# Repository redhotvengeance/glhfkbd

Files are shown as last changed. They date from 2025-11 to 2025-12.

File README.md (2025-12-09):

# glhfkbd

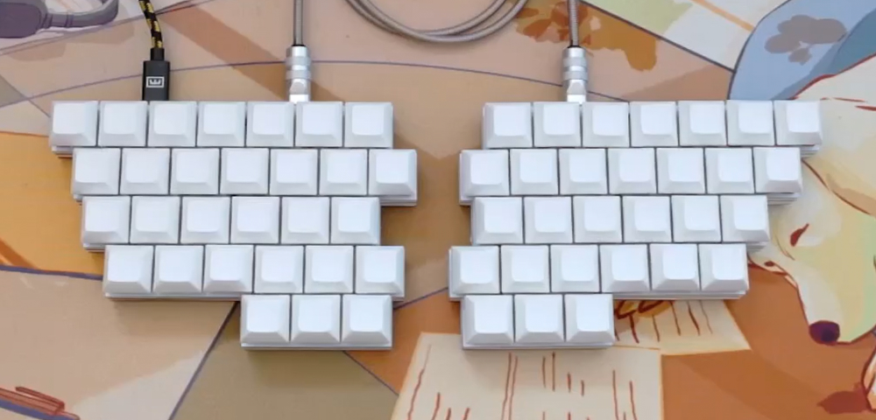
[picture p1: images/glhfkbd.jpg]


A custom, split keyboard.

Features:
- Extremely minimalist design -- no bevels, no edges, just keys!
- Split body, for da ergonomics
- Row-staggered, for da muscle memory
- A "Y" and "B" key on both halves, for da bad typists
- Supports hotswap MX sockets
- Fully embedded electronics -- no dev boards!
- USB-C for the wired interconnect -- no live TRRS shorts!
- Either side can act as the host
- Driven by QMK firmware and fully customizable

## PCB

The PCB is all one unit, despite both halves of the keyboard being asymmetrical. Mouse bites are used to easily separate pieces. All gerbers are provided in this repo.

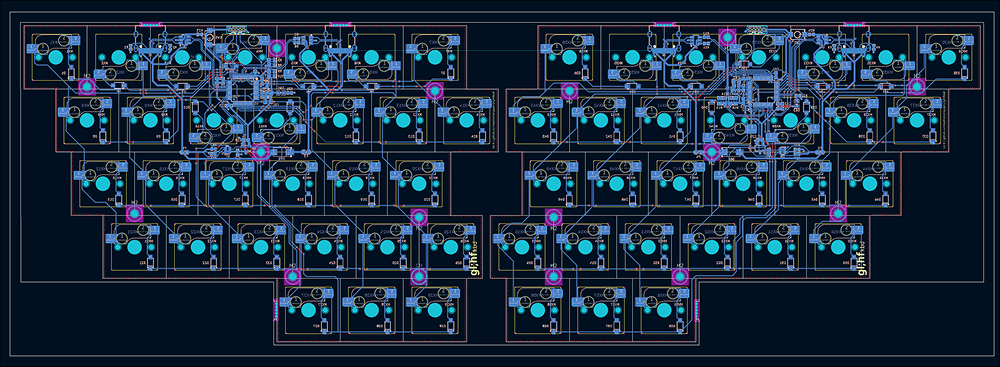
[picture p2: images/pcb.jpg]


All electronics are embedded into the board itself. This eliminates the need for a dev board, but requires assembly by a PCB manufacturer. BOM and position files are provided in this repo.

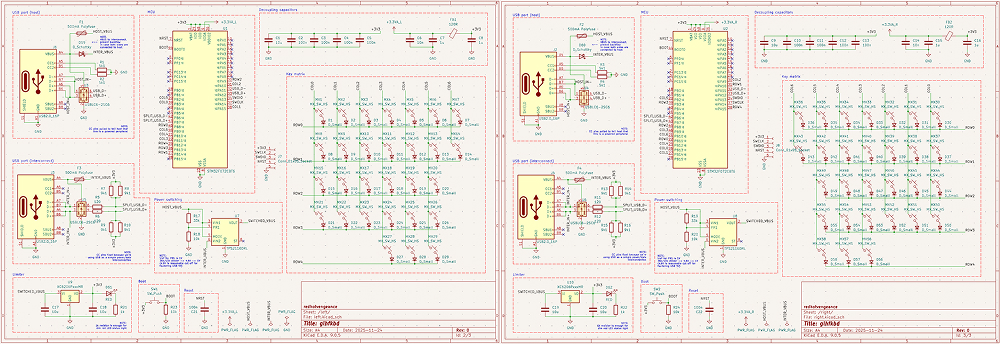
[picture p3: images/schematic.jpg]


## Case

All pieces for the case are provided as STEP files in this repo, with the exception of the switch plates, which are provided as PCB files so they can be manufactored in FR4.

### Switch plates (required)

Found in the `pcb` folder. Should be printed as non-copper and non-trace PCBs.

### Filler layer (optional)

3D printed layer that sites between the plates and PCBs (to fill the space between switches). Used for aesthetics and sound.

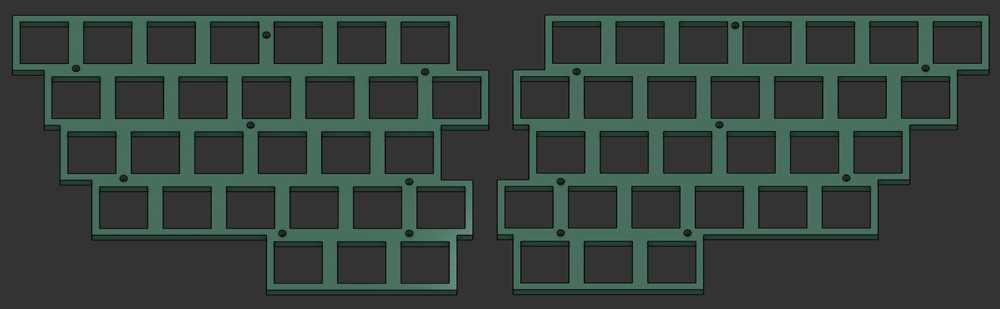
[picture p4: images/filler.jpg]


### Standoff layer (required)

Used to mount the PCBs and plates to the base. Can be easily 3D printed. Needs heat-set inserts added.

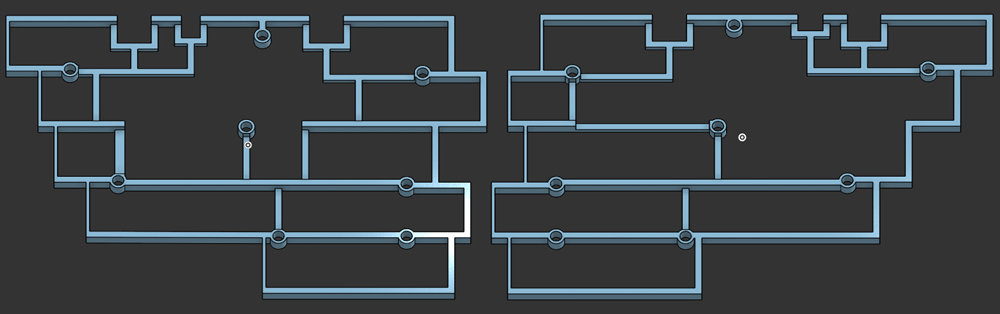
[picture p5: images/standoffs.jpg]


### Base (required)

Bottom of the keyboard. Can be 3D printed. Should have rubber feet added for stability.

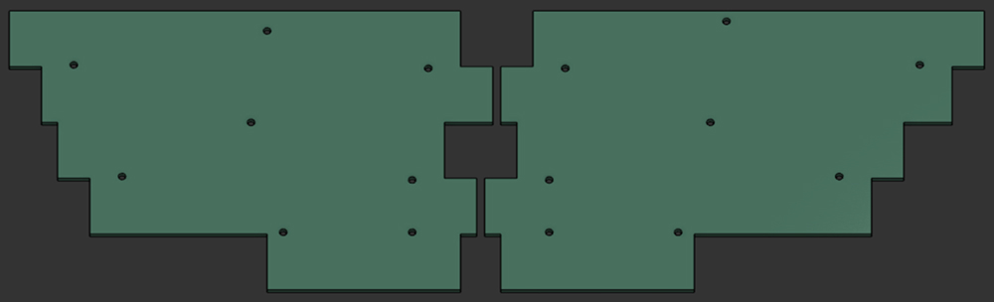
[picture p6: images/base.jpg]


As an upgrade, the base can be laser cut from metal. This adds weight, quality, and improved sound. I suggest using a ferrous metal (like carbon steel) so that each keyboard half can be easily attached to a magsafe stand for easy tenting.

## Sharing

Fully open source. Feel free to build it yourself.

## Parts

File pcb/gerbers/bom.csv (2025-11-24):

Designator | Footprint | Quantity | Value | LCSC Part #
C1, C17, C18, C19, C20, C9 | cap_10uf | 6 | 10u | C15525
C10, C11, C12, C13, C2, C21, C22, C3, C4, C5 | cap_100nf | 10 | 100n | C307331
C14, C6 | cap_10nf | 2 | 10n | C15195
C15, C16, C7, C8 | cap_1uf | 4 | 1u | C52923
D1, D10, D11, D12, D13, D14, D15, D16, D17, D18, D19, D2, D20, D21, D22, D23, D24, D25, D26, D27, D28, D29, D3, D30, D31, D32, D33, D34, D35, D36, D37, D38, D39, D4, D40, D41, D42, D43, D44, D45, D46, D47, D48, D49, D5, D50, D51, D52, D53, D54, D55, D56, D57, D58, D6, D7, D8, D9 | diode_sod123 | 58 | D_Small | C81598
D59, D60 | schottky | 2 | D_Schottky | C22452
D61, D62 | led | 2 | RED | C2286
F1, F2, F3, F4 | fuse_500ma | 4 | 500mA Polyfuse | C210357
FB1, FB2 | ferrite | 2 | 120R | C87063
J1, J2, J3, J4 | usb-c | 4 | USB2.0_16P | C165948
R1, R2, R3, R4 | res_5k1 | 4 | 5k1 | C25905
R10, R13, R14, R15, R16, R7, R8, R9 | res_9k1 | 8 | 9k1 | C23260
R11, R12, R5, R6 | res_120 | 4 | 120 | C25079
R17, R19 | res_33k | 2 | 33k | C25779
R18, R20, R23, R24 | res_10k | 4 | 10k | C25744
R21, R22 | res_1k | 2 | 1k | C11702
SW1, SW2 | switch | 2 | SW_Push | C720477
U1, U2 | stm32 | 2 | STM32F072CBT6 | C81720
U10, U9 | xc6206 | 2 | XC6206PxxxMR | C5446
U3, U4, U5, U6 | usblc6-2sc6 | 4 | USBLC6-2SC6 | C2827654
U7, U8 | tps2116drlr | 2 | TPS2116DRL | C3235557

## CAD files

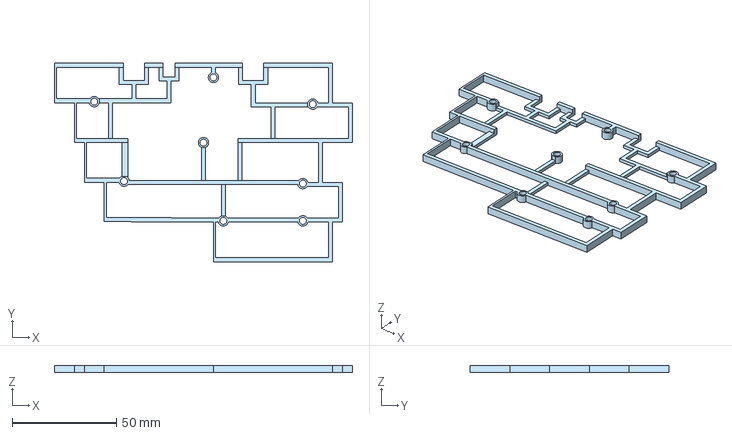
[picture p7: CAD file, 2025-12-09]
case/step/standoff_left.step
142.9 x 95.2 x 3.50 mm

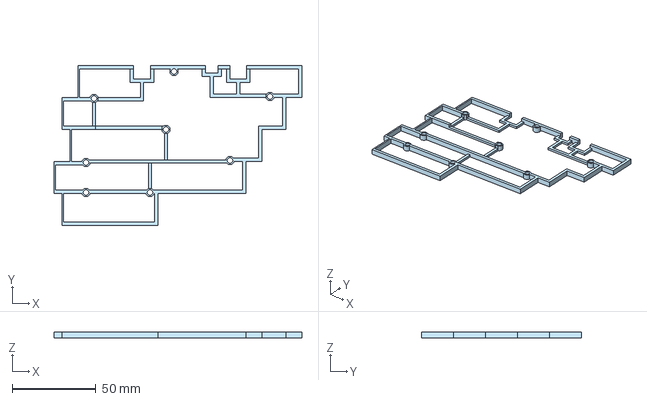
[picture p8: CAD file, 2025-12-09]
case/step/standoff_right.step
147.6 x 95.2 x 3.50 mm

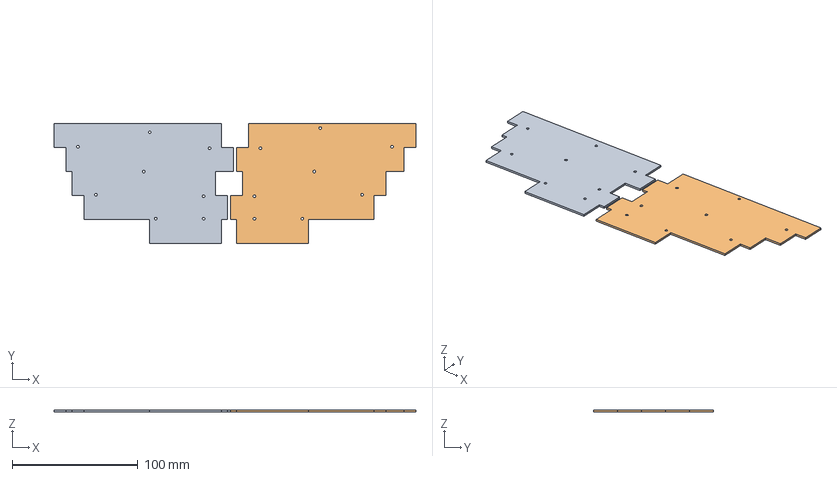
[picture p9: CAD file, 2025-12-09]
case/step/bottom.step
288.1 x 95.3 x 1.51 mm
bottom_PCB_1
bottom_PCB_2

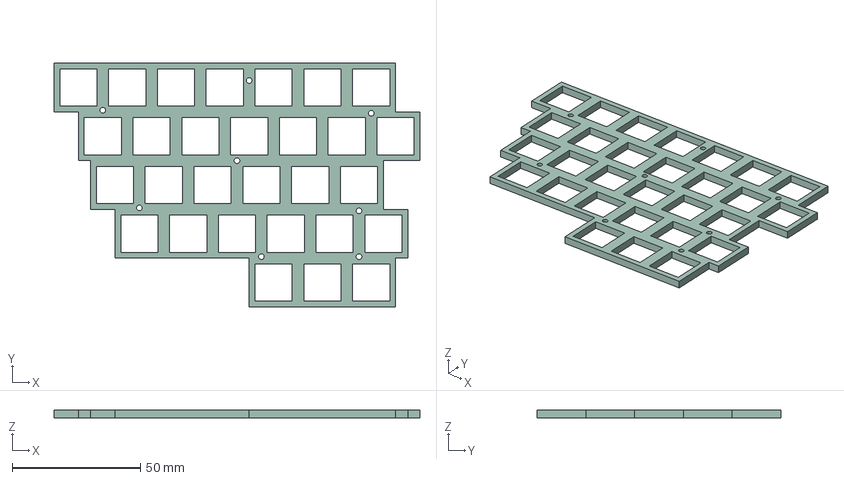
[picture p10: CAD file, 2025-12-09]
case/step/filler_left.step
142.9 x 95.3 x 3.00 mm

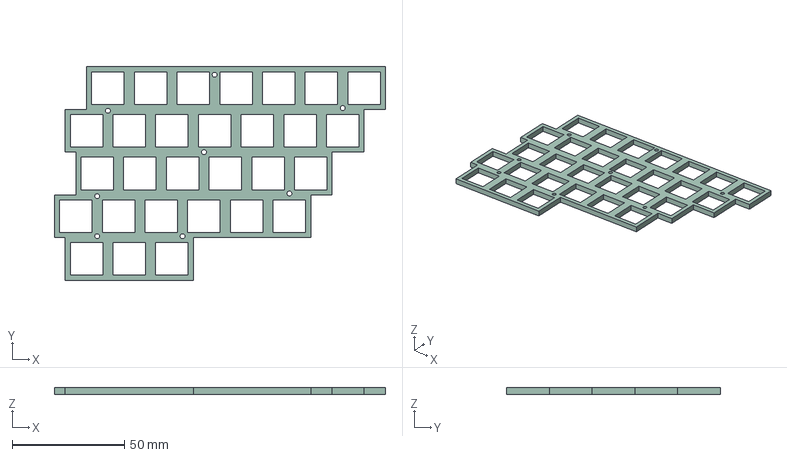
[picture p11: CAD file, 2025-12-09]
case/step/filler_right.step
147.6 x 95.2 x 3.00 mm

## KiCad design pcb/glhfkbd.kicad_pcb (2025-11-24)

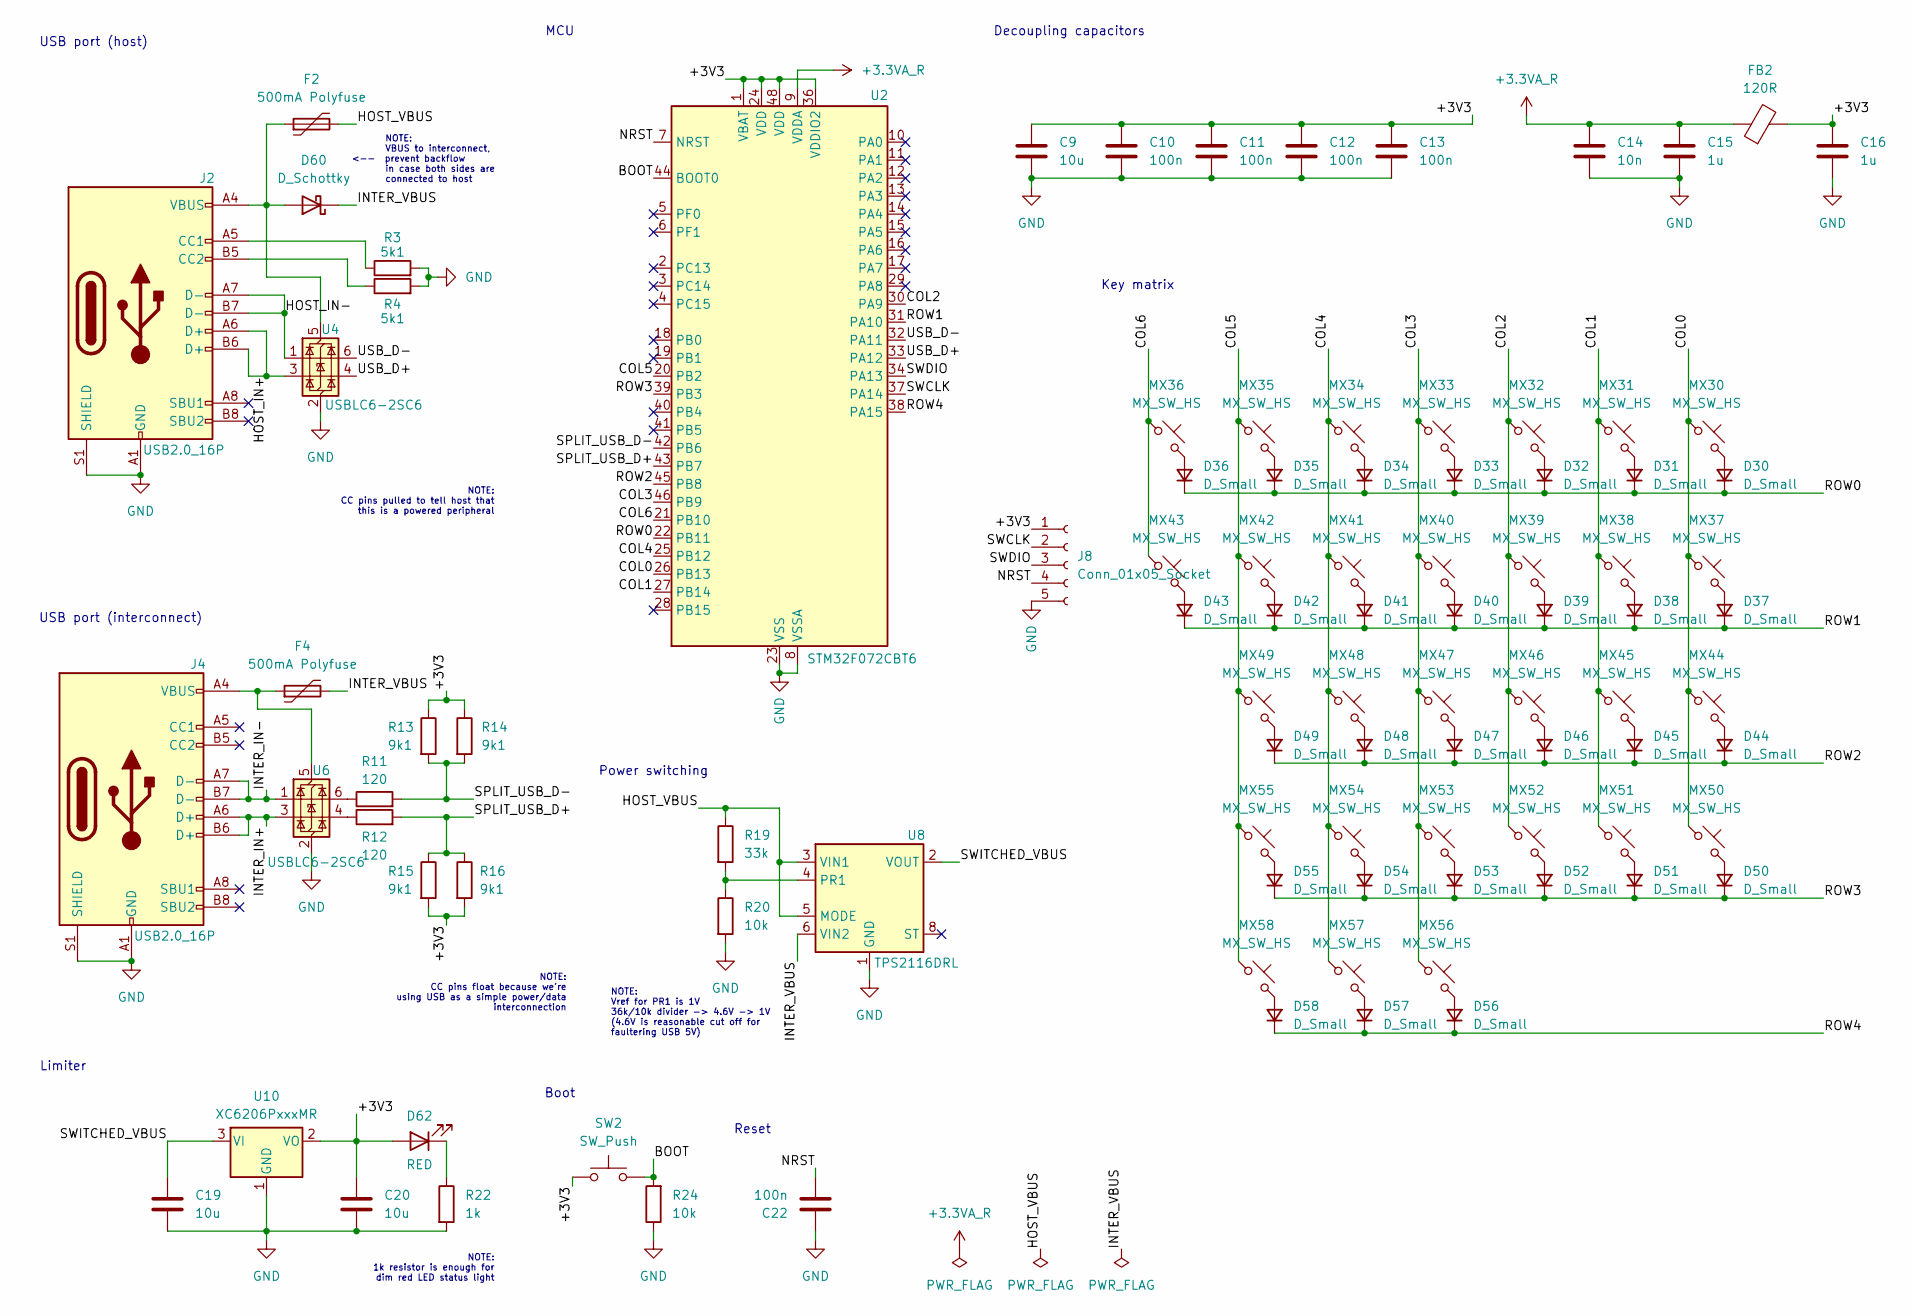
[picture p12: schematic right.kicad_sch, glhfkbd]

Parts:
C9, C19, C20: 10u; cap_10uf; Manufacturer Part CL05A106MQ5NUNC; LCSC C15525
C10, C11, C12, C13, C22: 100n; cap_100nf; Manufacturer Part CL05B104KB54PNC; LCSC C307331
C14: 10n; cap_10nf; Manufacturer Part CL05B103KB5NNNC; LCSC C15195
C15, C16: 1u; cap_1uf; Manufacturer Part CL05A105KA5NQNC; LCSC C52923
D30, D31, D32, D33, D34, D35, D36, D37, D38, D39, D40, D41, D42, D43, D44, D45, D46, D47, D48, D49, D50, D51, D52, D53, D54, D55, D56, D57, D58: D_Small; diode_sod123; Manufacturer Part 1N4148W; LCSC C81598
D60: D_Schottky; schottky; Manufacturer Part SS54; LCSC C22452
D62: RED; led; Manufacturer Part KT-0603R; LCSC C2286
F2, F4: 500mA Polyfuse; fuse_500ma; Manufacturer Part MF-FSMF050X-2; LCSC C210357
FB2: 120R; ferrite; Manufacturer Part BLM18SG260TN1D; LCSC C87063
J2, J4: USB2.0_16P; usb-c; Manufacturer Part TYPE-C-31-M-12; LCSC C165948
J8: Conn_01x05_Socket; PinHeader_1x05_P1.00mm_Vertical
MX30, MX31, MX32, MX33, MX34, MX35, MX36, MX37, MX38, MX39, MX40, MX41, MX42, MX43, MX44, MX45, MX46, MX47, MX48, MX49, MX50, MX51, MX52, MX53, MX54, MX55, MX56, MX57, MX58: MX_SW_HS; SW_MX_HS_CPG151101S11_1u
R3, R4: 5k1; res_5k1; Manufacturer Part 0402WGF5101TCE; LCSC C25905
R11, R12: 120; res_120; LCSC C25079
R13, R14, R15, R16: 9k1; res_9k1; LCSC C23260
R19: 33k; res_33k; Manufacturer Part 0402WGF3302TCE; LCSC C25779
R20, R24: 10k; res_10k; Manufacturer Part 0402WGF1002TCE; LCSC C25744
R22: 1k; res_1k; Manufacturer Part 0402WGF1001TCE; LCSC C11702
SW2: SW_Push; switch; Manufacturer Part TS-1088-AR02016; LCSC C720477
U2: STM32F072CBT6; stm32; Manufacturer Part STM32F072CBT6; LCSC C81720
U4, U6: USBLC6-2SC6; usblc6-2sc6; Manufacturer Part USBLC6-2SC6; LCSC C2827654
U8: TPS2116DRL; tps2116drlr; Manufacturer Part TPS2116DRLR; LCSC C3235557
U10: XC6206PxxxMR; xc6206; Manufacturer Part XC6206P332MR-G; LCSC C5446

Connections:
+3.3VA_R: C14.1, C15.1, FB2.1, U2.9 (VDDA)
/right/+3V3: C9.1, C10.1, C11.1, C12.1, C13.1, C16.1, C20.1, D62.2 (A), FB2.2, J8.1, R13.1, R14.1, R15.2, R16.2, SW2.1, U2.1 (VBAT), U2.24 (VDD), U2.36 (VDDIO2), U2.48 (VDD), U10.2 (VO)
/right/BOOT: R24.2, SW2.2, U2.44 (BOOT0)
/right/COL0: MX30.1, MX37.1, MX44.1, MX50.1, U2.26 (PB13)
/right/COL1: MX31.1, MX38.1, MX45.1, MX51.1, U2.27 (PB14)
/right/COL2: MX32.1, MX39.1, MX46.1, MX52.1, U2.30 (PA9)
/right/COL3: MX33.1, MX40.1, MX47.1, MX53.1, MX56.1, U2.46 (PB9)
/right/COL4: MX34.1, MX41.1, MX48.1, MX54.1, MX57.1, U2.25 (PB12)
/right/COL5: MX35.1, MX42.1, MX49.1, MX55.1, MX58.1, U2.20 (PB2)
/right/COL6: MX36.1, MX43.1, U2.21 (PB10)
/right/HOST_IN+: J2.A6 (D+), J2.B6 (D+), U4.3 (I/O2)
/right/HOST_IN-: J2.A7 (D-), J2.B7 (D-), U4.1 (I/O1)
/right/HOST_VBUS: F2.2, R19.1, U8.3 (VIN1), U8.5 (MODE)
/right/INTER_IN+: J4.A6 (D+), J4.B6 (D+), U6.3 (I/O2)
/right/INTER_IN-: J4.A7 (D-), J4.B7 (D-), U6.1 (I/O1)
/right/INTER_VBUS: D60.1 (K), F4.2, U8.6 (VIN2)
/right/NRST: C22.1, J8.4, U2.7 (NRST)
/right/ROW0: D30.1 (K), D31.1 (K), D32.1 (K), D33.1 (K), D34.1 (K), D35.1 (K), D36.1 (K), U2.22 (PB11)
/right/ROW1: D37.1 (K), D38.1 (K), D39.1 (K), D40.1 (K), D41.1 (K), D42.1 (K), D43.1 (K), U2.31 (PA10)
/right/ROW2: D44.1 (K), D45.1 (K), D46.1 (K), D47.1 (K), D48.1 (K), D49.1 (K), U2.45 (PB8)
/right/ROW3: D50.1 (K), D51.1 (K), D52.1 (K), D53.1 (K), D54.1 (K), D55.1 (K), U2.39 (PB3)
/right/ROW4: D56.1 (K), D57.1 (K), D58.1 (K), U2.38 (PA15)
/right/SPLIT_USB_D+: R12.2, R15.1, R16.1, U2.43 (PB7)
/right/SPLIT_USB_D-: R11.2, R13.2, R14.2, U2.42 (PB6)
/right/SWCLK: J8.2, U2.37 (PA14)
/right/SWDIO: J8.3, U2.34 (PA13)
/right/SWITCHED_VBUS: C19.1, U8.2 (VOUT), U8.7 (VOUT), U10.3 (VI)
/right/USB_D+: U2.33 (PA12), U4.4 (I/O2)
/right/USB_D-: U2.32 (PA11), U4.6 (I/O1)
GND: C9.2, C10.2, C11.2, C12.2, C13.2, C14.2, C15.2, C16.2, C19.2, C20.2, C22.2, J2.A1 (GND), J2.A12 (GND), J2.B1 (GND), J2.B12 (GND), J2.S1 (SHIELD), J4.A1 (GND), J4.A12 (GND), J4.B1 (GND), J4.B12 (GND), J4.S1 (SHIELD), J8.5, R3.2, R4.2, R20.2, R22.2, R24.1, U2.8 (VSSA), U2.23 (VSS), U2.35 (VSS), U2.47 (VSS), U4.2 (GND), U6.2 (GND), U8.1 (GND), U10.1 (GND); also elsewhere on the board
unnamed: D30.2 (A), MX30.2
unnamed: D31.2 (A), MX31.2
unnamed: D32.2 (A), MX32.2
unnamed: D33.2 (A), MX33.2
unnamed: D34.2 (A), MX34.2
unnamed: D35.2 (A), MX35.2
unnamed: D36.2 (A), MX36.2
unnamed: D37.2 (A), MX37.2
unnamed: D38.2 (A), MX38.2
unnamed: D39.2 (A), MX39.2
unnamed: D40.2 (A), MX40.2
unnamed: D41.2 (A), MX41.2
unnamed: D42.2 (A), MX42.2
unnamed: D43.2 (A), MX43.2
unnamed: D44.2 (A), MX44.2
unnamed: D45.2 (A), MX45.2
unnamed: D46.2 (A), MX46.2
unnamed: D47.2 (A), MX47.2
unnamed: D48.2 (A), MX48.2
unnamed: D49.2 (A), MX49.2
unnamed: D50.2 (A), MX50.2
unnamed: D51.2 (A), MX51.2
unnamed: D52.2 (A), MX52.2
unnamed: D53.2 (A), MX53.2
unnamed: D54.2 (A), MX54.2
unnamed: D55.2 (A), MX55.2
unnamed: D56.2 (A), MX56.2
unnamed: D57.2 (A), MX57.2
unnamed: D58.2 (A), MX58.2
unnamed: D60.2 (A), F2.1, J2.A4 (VBUS), J2.A9 (VBUS), J2.B4 (VBUS), J2.B9 (VBUS), U4.5 (VBUS)
unnamed: D62.1 (K), R22.1
unnamed: J2.A5 (CC1), R3.1
unnamed: J2.B5 (CC2), R4.1
unnamed: R11.1, U6.6 (I/O1)
unnamed: R12.1, U6.4 (I/O2)
unnamed: F4.1, J4.A4 (VBUS), J4.A9 (VBUS), J4.B4 (VBUS), J4.B9 (VBUS), U6.5 (VBUS)
unnamed: R19.2, R20.1, U8.4 (PR1)

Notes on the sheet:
USB port (interconnect)
NOTE: CC pins float because we're using USB as a simple power/data interconnection
Power switching
USB port (host)
Decoupling capacitors
NOTE: VBUS to interconnect, <-- prevent backflow in case both sides are connected to host
Key matrix
NOTE: 1k resistor is enough for dim red LED status light
NOTE: Vref for PR1 is 1V 36k/10k divider -> 4.6V -> 1V (4.6V is reasonable cut off for faultering USB 5V)
Reset
NOTE: CC pins pulled to tell host that this is a powered peripheral
Limiter
MCU
Boot

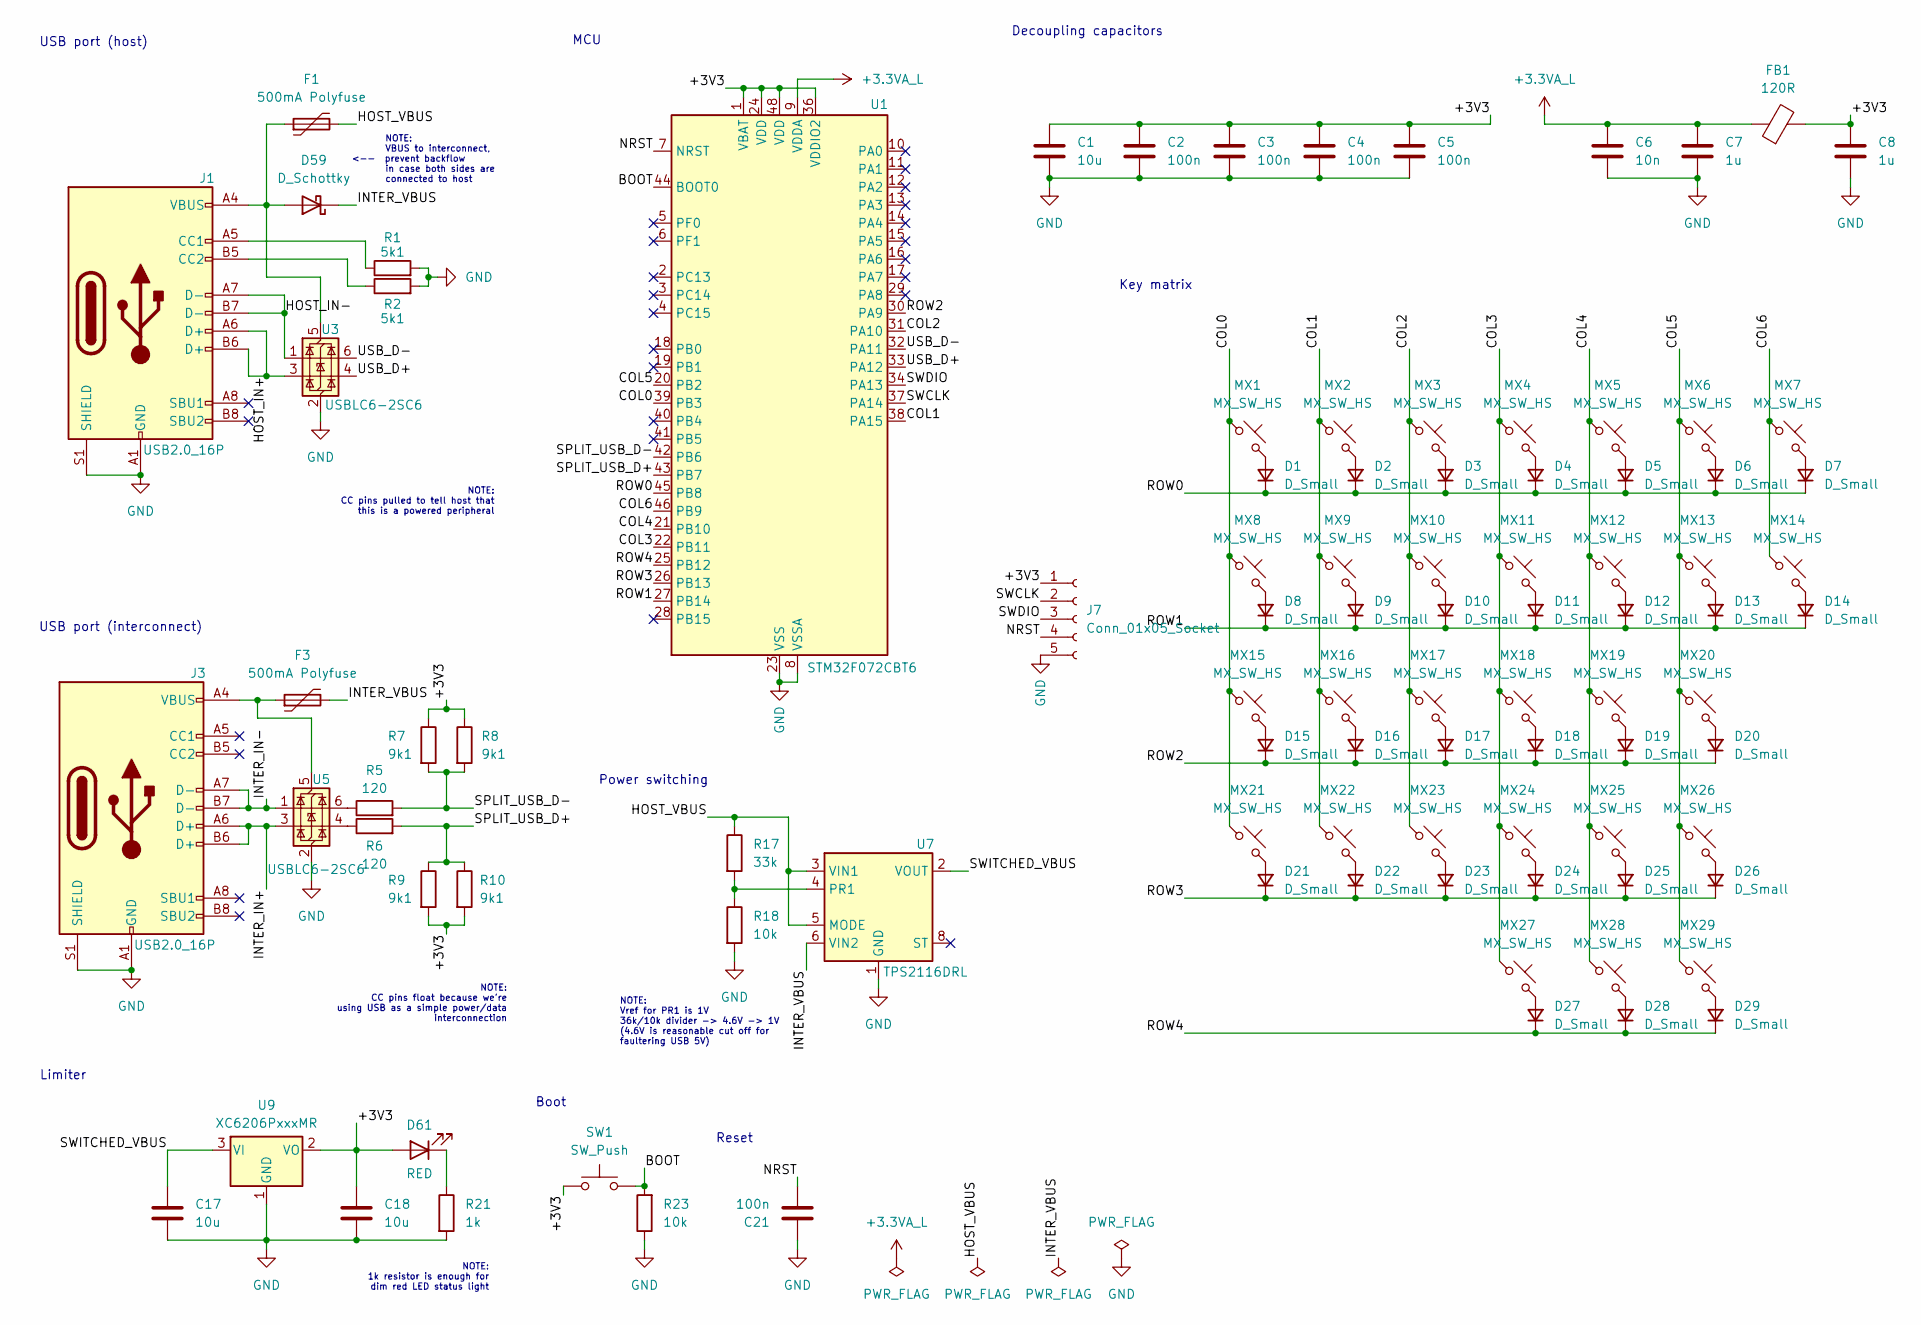
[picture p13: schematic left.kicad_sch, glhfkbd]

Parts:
C1, C17, C18: 10u; cap_10uf; Manufacturer Part CL05A106MQ5NUNC; LCSC C15525
C2, C3, C4, C5, C21: 100n; cap_100nf; Manufacturer Part CL05B104KB54PNC; LCSC C307331
C6: 10n; cap_10nf; Manufacturer Part CL05B103KB5NNNC; LCSC C15195
C7, C8: 1u; cap_1uf; Manufacturer Part CL05A105KA5NQNC; LCSC C52923
D1, D2, D3, D4, D5, D6, D7, D8, D9, D10, D11, D12, D13, D14, D15, D16, D17, D18, D19, D20, D21, D22, D23, D24, D25, D26, D27, D28, D29: D_Small; diode_sod123; Manufacturer Part 1N4148W; LCSC C81598
D59: D_Schottky; schottky; Manufacturer Part SS54; LCSC C22452
D61: RED; led; Manufacturer Part KT-0603R; LCSC C2286
F1, F3: 500mA Polyfuse; fuse_500ma; Manufacturer Part MF-FSMF050X-2; LCSC C210357
FB1: 120R; ferrite; Manufacturer Part BLM18SG260TN1D; LCSC C87063
J1, J3: USB2.0_16P; usb-c; Manufacturer Part TYPE-C-31-M-12; LCSC C165948
J7: Conn_01x05_Socket; PinHeader_1x05_P1.00mm_Vertical
MX1, MX2, MX3, MX4, MX5, MX6, MX7, MX8, MX9, MX10, MX11, MX12, MX13, MX14, MX15, MX16, MX17, MX18, MX19, MX20, MX21, MX22, MX23, MX24, MX25, MX26, MX27, MX28, MX29: MX_SW_HS; SW_MX_HS_CPG151101S11_1u
R1, R2: 5k1; res_5k1; Manufacturer Part 0402WGF5101TCE; LCSC C25905
R5, R6: 120; res_120; LCSC C25079
R7, R8, R9, R10: 9k1; res_9k1; LCSC C23260
R17: 33k; res_33k; Manufacturer Part 0402WGF3302TCE; LCSC C25779
R18, R23: 10k; res_10k; Manufacturer Part 0402WGF1002TCE; LCSC C25744
R21: 1k; res_1k; Manufacturer Part 0402WGF1001TCE; LCSC C11702
SW1: SW_Push; switch; Manufacturer Part TS-1088-AR02016; LCSC C720477
U1: STM32F072CBT6; stm32; Manufacturer Part STM32F072CBT6; LCSC C81720
U3, U5: USBLC6-2SC6; usblc6-2sc6; Manufacturer Part USBLC6-2SC6; LCSC C2827654
U7: TPS2116DRL; tps2116drlr; Manufacturer Part TPS2116DRLR; LCSC C3235557
U9: XC6206PxxxMR; xc6206; Manufacturer Part XC6206P332MR-G; LCSC C5446

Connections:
+3.3VA_L: C6.1, C7.1, FB1.1, U1.9 (VDDA)
/left/+3V3: C1.1, C2.1, C3.1, C4.1, C5.1, C8.1, C18.1, D61.2 (A), FB1.2, J7.1, R7.1, R8.1, R9.2, R10.2, SW1.1, U1.1 (VBAT), U1.24 (VDD), U1.36 (VDDIO2), U1.48 (VDD), U9.2 (VO)
/left/BOOT: R23.2, SW1.2, U1.44 (BOOT0)
/left/COL0: MX1.1, MX8.1, MX15.1, MX21.1, U1.39 (PB3)
/left/COL1: MX2.1, MX9.1, MX16.1, MX22.1, U1.38 (PA15)
/left/COL2: MX3.1, MX10.1, MX17.1, MX23.1, U1.31 (PA10)
/left/COL3: MX4.1, MX11.1, MX18.1, MX24.1, MX27.1, U1.22 (PB11)
/left/COL4: MX5.1, MX12.1, MX19.1, MX25.1, MX28.1, U1.21 (PB10)
/left/COL5: MX6.1, MX13.1, MX20.1, MX26.1, MX29.1, U1.20 (PB2)
/left/COL6: MX7.1, MX14.1, U1.46 (PB9)
/left/HOST_IN+: J1.A6 (D+), J1.B6 (D+), U3.3 (I/O2)
/left/HOST_IN-: J1.A7 (D-), J1.B7 (D-), U3.1 (I/O1)
/left/HOST_VBUS: F1.2, R17.1, U7.3 (VIN1), U7.5 (MODE)
/left/INTER_IN+: J3.A6 (D+), J3.B6 (D+), U5.3 (I/O2)
/left/INTER_IN-: J3.A7 (D-), J3.B7 (D-), U5.1 (I/O1)
/left/INTER_VBUS: D59.1 (K), F3.2, U7.6 (VIN2)
/left/NRST: C21.1, J7.4, U1.7 (NRST)
/left/ROW0: D1.1 (K), D2.1 (K), D3.1 (K), D4.1 (K), D5.1 (K), D6.1 (K), D7.1 (K), U1.45 (PB8)
/left/ROW1: D8.1 (K), D9.1 (K), D10.1 (K), D11.1 (K), D12.1 (K), D13.1 (K), D14.1 (K), U1.27 (PB14)
/left/ROW2: D15.1 (K), D16.1 (K), D17.1 (K), D18.1 (K), D19.1 (K), D20.1 (K), U1.30 (PA9)
/left/ROW3: D21.1 (K), D22.1 (K), D23.1 (K), D24.1 (K), D25.1 (K), D26.1 (K), U1.26 (PB13)
/left/ROW4: D27.1 (K), D28.1 (K), D29.1 (K), U1.25 (PB12)
/left/SPLIT_USB_D+: R6.2, R9.1, R10.1, U1.43 (PB7)
/left/SPLIT_USB_D-: R5.2, R7.2, R8.2, U1.42 (PB6)
/left/SWCLK: J7.2, U1.37 (PA14)
/left/SWDIO: J7.3, U1.34 (PA13)
/left/SWITCHED_VBUS: C17.1, U7.2 (VOUT), U7.7 (VOUT), U9.3 (VI)
/left/USB_D+: U1.33 (PA12), U3.4 (I/O2)
/left/USB_D-: U1.32 (PA11), U3.6 (I/O1)
GND: C1.2, C2.2, C3.2, C4.2, C5.2, C6.2, C7.2, C8.2, C17.2, C18.2, C21.2, J1.A1 (GND), J1.A12 (GND), J1.B1 (GND), J1.B12 (GND), J1.S1 (SHIELD), J3.A1 (GND), J3.A12 (GND), J3.B1 (GND), J3.B12 (GND), J3.S1 (SHIELD), J7.5, R1.2, R2.2, R18.2, R21.2, R23.1, U1.8 (VSSA), U1.23 (VSS), U1.35 (VSS), U1.47 (VSS), U3.2 (GND), U5.2 (GND), U7.1 (GND), U9.1 (GND); also elsewhere on the board
unnamed: D1.2 (A), MX1.2
unnamed: D2.2 (A), MX2.2
unnamed: D3.2 (A), MX3.2
unnamed: D4.2 (A), MX4.2
unnamed: D5.2 (A), MX5.2
unnamed: D6.2 (A), MX6.2
unnamed: D7.2 (A), MX7.2
unnamed: D8.2 (A), MX8.2
unnamed: D9.2 (A), MX9.2
unnamed: D10.2 (A), MX10.2
unnamed: D11.2 (A), MX11.2
unnamed: D12.2 (A), MX12.2
unnamed: D13.2 (A), MX13.2
unnamed: D14.2 (A), MX14.2
unnamed: D15.2 (A), MX15.2
unnamed: D16.2 (A), MX16.2
unnamed: D17.2 (A), MX17.2
unnamed: D18.2 (A), MX18.2
unnamed: D19.2 (A), MX19.2
unnamed: D20.2 (A), MX20.2
unnamed: D21.2 (A), MX21.2
unnamed: D22.2 (A), MX22.2
unnamed: D23.2 (A), MX23.2
unnamed: D24.2 (A), MX24.2
unnamed: D25.2 (A), MX25.2
unnamed: D26.2 (A), MX26.2
unnamed: D27.2 (A), MX27.2
unnamed: D28.2 (A), MX28.2
unnamed: D29.2 (A), MX29.2
unnamed: D59.2 (A), F1.1, J1.A4 (VBUS), J1.A9 (VBUS), J1.B4 (VBUS), J1.B9 (VBUS), U3.5 (VBUS)
unnamed: D61.1 (K), R21.1
unnamed: J1.A5 (CC1), R1.1
unnamed: J1.B5 (CC2), R2.1
unnamed: R5.1, U5.6 (I/O1)
unnamed: R6.1, U5.4 (I/O2)
unnamed: F3.1, J3.A4 (VBUS), J3.A9 (VBUS), J3.B4 (VBUS), J3.B9 (VBUS), U5.5 (VBUS)
unnamed: R17.2, R18.1, U7.4 (PR1)

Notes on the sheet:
NOTE: CC pins float because we're using USB as a simple power/data interconnection
Power switching
NOTE: CC pins pulled to tell host that this is a powered peripheral
NOTE: 1k resistor is enough for dim red LED status light
Decoupling capacitors
USB port (host)
Reset
NOTE: VBUS to interconnect, <-- prevent backflow in case both sides are connected to host
NOTE: Vref for PR1 is 1V 36k/10k divider -> 4.6V -> 1V (4.6V is reasonable cut off for faultering USB 5V)
Key matrix
USB port (interconnect)
Boot
MCU
Limiter

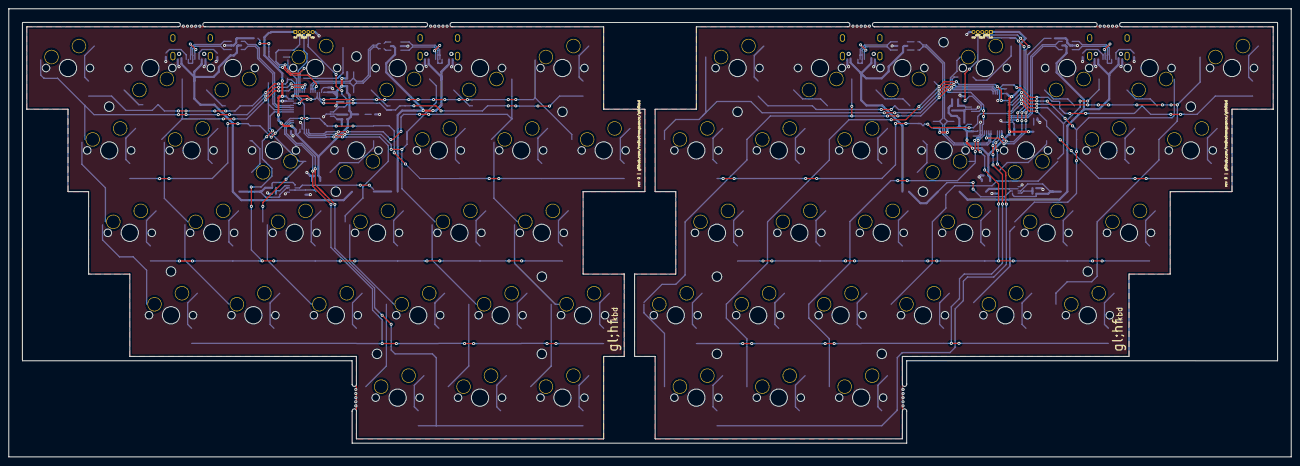
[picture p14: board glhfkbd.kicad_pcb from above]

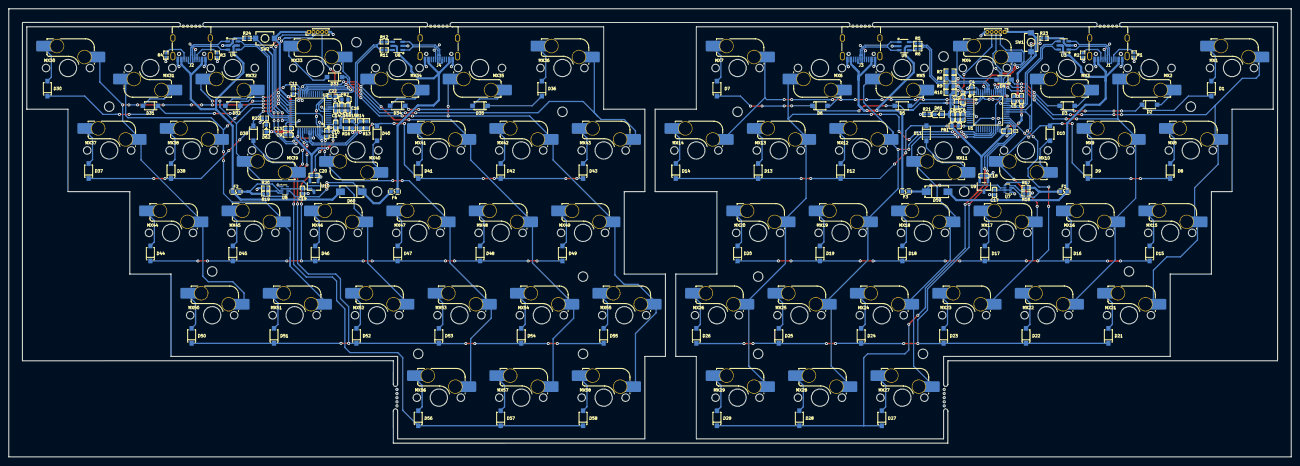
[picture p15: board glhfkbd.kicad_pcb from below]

Board: 2 copper layers, 296.5 x 103.6 mm, 206 parts (191 on the bottom side), 133 nets.

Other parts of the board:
M2, M2#2, M2#3, M2#4, M2#5, M2#6, M2#7, M2#8, M2#9, M2#10, M2#11, M2#12, M2#13, M2#14, M2#15, M2#16: MountingHole_2.2mm_M2

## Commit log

2025-11-24 Add pcb
    [glhfkbd.kicad_pcb, glhfkbd.kicad_sch, left.kicad_sch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]
2025-11-24 Add case
    [filler_left.kicad_pcb, filler_right.kicad_pcb]
2025-11-24 Add gerbers
    [bom.csv, positions.csv]
2025-12-09 Add step files
    [bottom.step, filler_left.step, filler_right.step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]
